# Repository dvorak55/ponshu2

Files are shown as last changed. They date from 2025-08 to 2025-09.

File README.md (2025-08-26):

# ponshu2
The first keyboard in progress by Natural Keyboard Studio Murahana《叢華》.

## プロトタイプ写真  
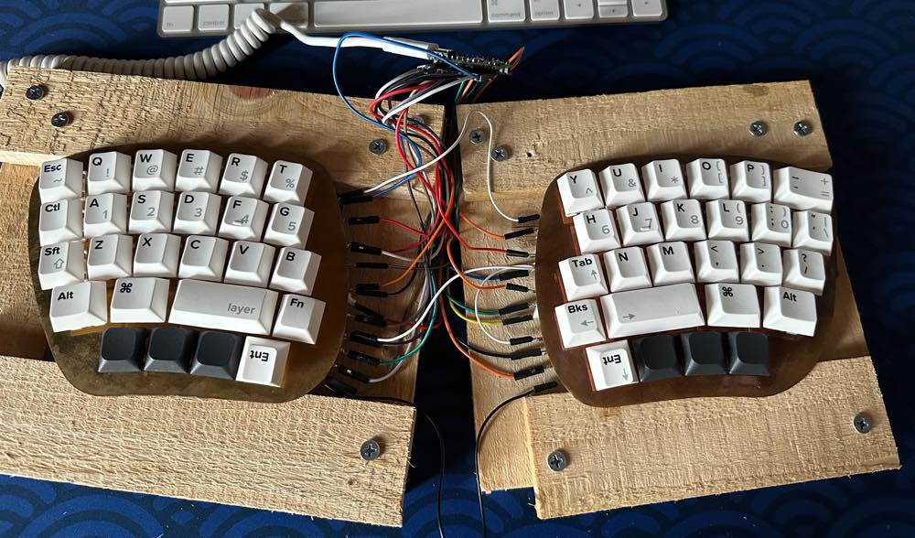
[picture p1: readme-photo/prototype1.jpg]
prototype


自作キーボードを作っています、t-miyajimaです。  
現在、新プロジェクトを進めております。  
新プロジェクトの名前は『Ponshu2（仮）』です。  
これは、以下の特徴を持つキーボードを製造し、販売することが目的です。
- スタイリッシュで使いやすいキーボード
- レイヤードキーボードへの移行が簡単なキー配列
- 修理しやく、長年使い続けられるキーボード
- 配線は基板に頼らず、PCB部分をなるべく少なくする
- 製品全体の廃棄・製造時の環境負荷をなるべく低くする

# 環境負荷の低減
私は、2022年10月から2024年11月にかけて、自作キーボードを作るための工房を自作しました。  
その際に強く思ったのは、前世代の人間が残した遺物は、全て次世代の人間に受け継がれるのだ、ということです。  
そして、受け継がれた不要な遺物を片付けるのは、非常に大変だ、と実感しました。

次世代の人間のために不要な遺物をなるべく残さないようにする活動は、素晴らしいと思います。  
例えば、不要なものを分別してリサイクルすること。  
例えば、ゴミを捨てる際、処分に困るものが発生しないように工夫して物を製造すること。  
例えば、リサイクルしやすいように製造物に含有されるものを明示すること。  
私は、それらに取り組む人たちのことを非常に尊敬しています。

# 自然素材を用いた工房
私が自作したキーボード工房も、そのうち遺物になります。  
だから私は、工房を形作る素材に、自然素材を選びました。  
構造材には、鉄と木材（できる限り接着剤を含まない無垢材）を使用しました。  
断熱材には、炭、動物の毛（羊毛、羽毛）、綿や絹、紙を使用しました。  
これらは自然に還りやすく、片付けがしやすいです。  
また、再利用もしやすいので、次世代の人間がこうむる負担が減ります。  

# キーボードの目標
キーボードに用いる材料も、なるべく自然素材を多く使います。  
現在の私の能力では、コンピュータチップ周辺についてはPCBを使わざるを得ませんが、なるべくサイズを小さくします。  
キーボードのスイッチを保持するプレートには単純な金属を、キーボードのケースには木材を、配線には塩素等のハロゲンを含まないハロゲンフリー電線を、ハンダは鉛フリーハンダを、それぞれ用いる予定です。  
将来的に、より多くの部品を自然素材に置き換えることを目指しております。

# 進捗状況
2025年8月末の時点で、以下を進めております。
- 木材のケースへ取り付けやすく、配線しやすい基板の設計を開始
- キーボードプレートを木材のケースへ取り付けるための、真鍮ネジの選定
- 環境負荷の少ないハロゲンフリー電線の調達

また、以下は完了しております。
- キーボードのキーレイアウト
- キーボードプレートの試作
- キーキャップの試作
- Vialファームウェアの作成
- 試作機の動作テスト（この文章も試作機でタイプしております）

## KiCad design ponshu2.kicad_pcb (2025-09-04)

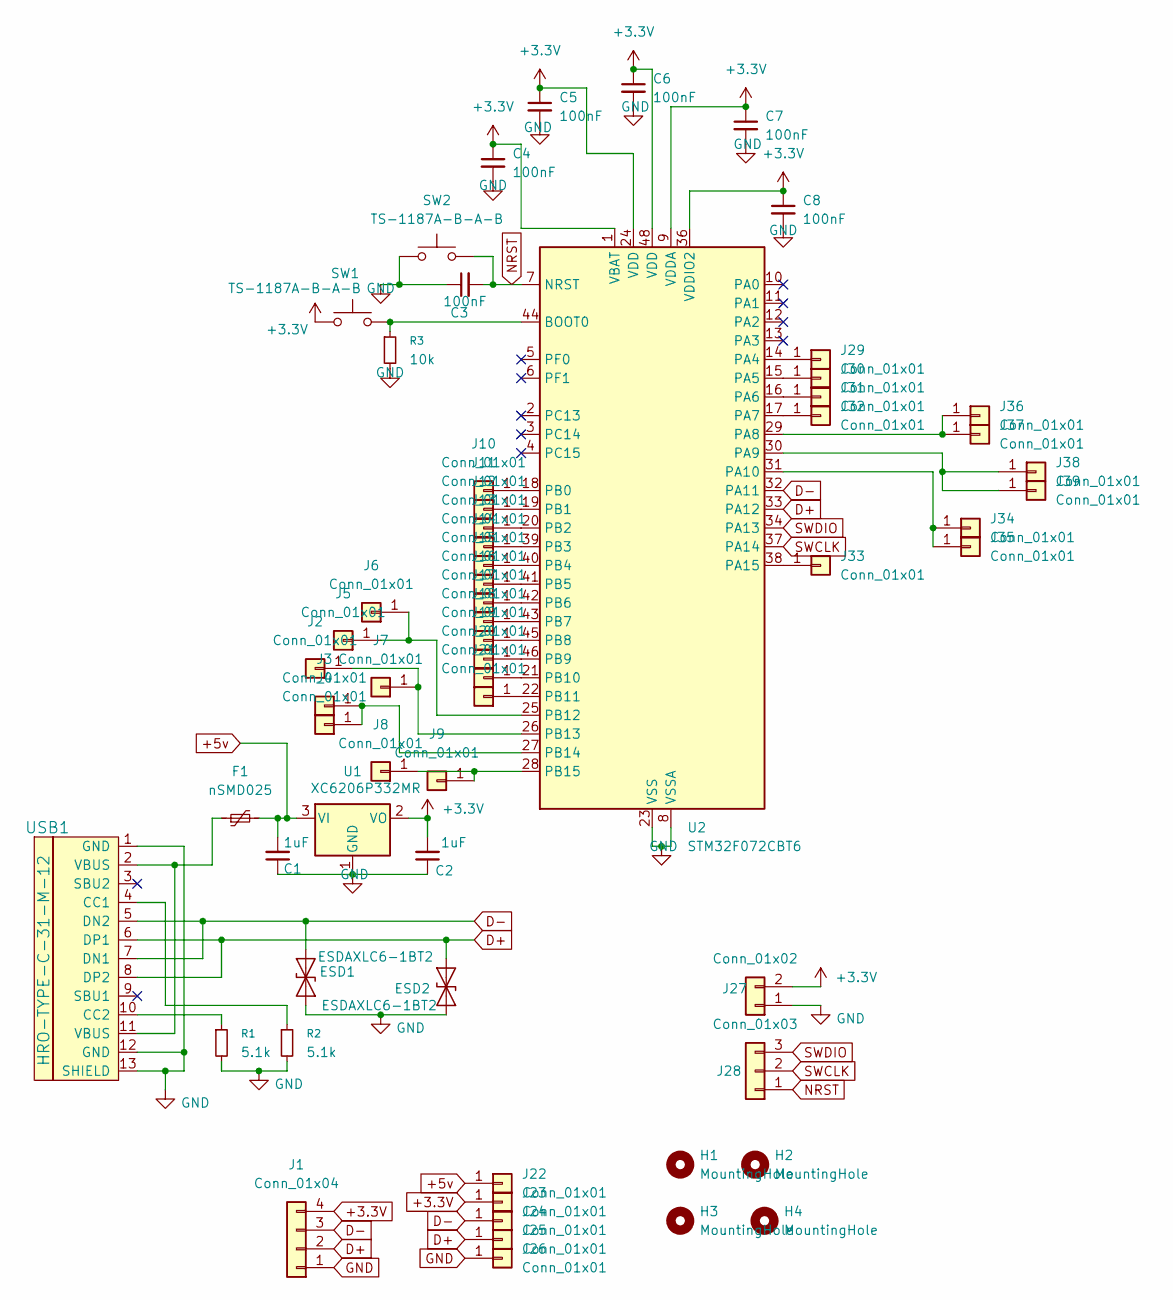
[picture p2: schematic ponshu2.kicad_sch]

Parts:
C1, C2: 1uF; C_0603_1608Metric
C3, C4, C5, C6, C7, C8: 100nF; C_0402_1005Metric
ESD1, ESD2: ESDAXLC6-1BT2; D_0402_1005Metric
F1: nSMD025; Fuse_1206_3216Metric
H1, H2, H3, H4: MountingHole; MountingHole_2.5mm
J1: Conn_01x04; PinHeader_1x04_P2.54mm_Vertical
J2, J3, J4, J5, J6, J7, J8, J9, J10, J11, J12, J13, J14, J15, J16, J17, J18, J19, J20, J21, J22, J23, J24, J25, J26, J29, J30, J31, J32, J33, J34, J35, J36, J37, J38, J39: Conn_01x01; PinHeader_1x01_P2.54mm_Vertical
J27: Conn_01x02; PinHeader_1x02_P2.54mm_Vertical
J28: Conn_01x03; PinHeader_1x03_P2.54mm_Vertical
R1, R2: 5.1k; R_0603_1608Metric
R3: 10k; R_0603_1608Metric
SW1, SW2: TS-1187A-B-A-B; SKQGADE010
U1: XC6206P332MR; SOT-23
U2: STM32F072CBT6; LQFP-48_7x7mm_P0.5mm
USB1: HRO-TYPE-C-31-M-12; HRO-TYPE-C-31-M-12-HandSoldering

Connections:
+3.3V: C2.2, C4.1, C5.1, C6.1, C7.1, C8.1, J1.4, J23.1, J27.2, SW1.1, U1.2 (VO), U2.1 (VBAT), U2.9 (VDDA), U2.24 (VDD), U2.36 (VDDIO2), U2.48 (VDD)
+5v: C1.2, F1.2, J22.1, U1.3 (VI)
D+: ESD2.2 (A2), J1.2, J25.1, U2.33 (PA12), USB1.6 (DP1), USB1.8 (DP2)
D-: ESD1.2 (A2), J1.3, J24.1, U2.32 (PA11), USB1.5 (DN2), USB1.7 (DN1)
GND: C1.1, C2.1, C3.1, C4.2, C5.2, C6.2, C7.2, C8.2, ESD1.1 (A1), ESD2.1 (A1), J1.1, J26.1, J27.1, R1.2, R2.2, R3.2, SW2.1, U1.1 (GND), U2.8 (VSSA), U2.23 (VSS), U2.35 (VSS), U2.47 (VSS), USB1.1 (GND), USB1.12 (GND), USB1.13 (SHIELD)
NRST: C3.2, J28.1, SW2.2, U2.7 (NRST)
unnamed: F1.1, USB1.2 (VBUS), USB1.11 (VBUS)
unnamed: J2.1, J7.1, U2.26 (PB13)
unnamed: J3.1, J4.1, U2.27 (PB14)
unnamed: J5.1, J6.1, U2.25 (PB12)
unnamed: J8.1, J9.1, U2.28 (PB15)
unnamed: J10.1, U2.18 (PB0)
unnamed: J11.1, U2.19 (PB1)
unnamed: J12.1, U2.20 (PB2)
unnamed: J13.1, U2.39 (PB3)
unnamed: J14.1, U2.40 (PB4)
unnamed: J15.1, U2.41 (PB5)
unnamed: J16.1, U2.42 (PB6)
unnamed: J17.1, U2.43 (PB7)
unnamed: J18.1, U2.45 (PB8)
unnamed: J19.1, U2.46 (PB9)
unnamed: J20.1, U2.21 (PB10)
unnamed: J21.1, U2.22 (PB11)
unnamed: J29.1, U2.14 (PA4)
unnamed: J30.1, U2.15 (PA5)
unnamed: J31.1, U2.16 (PA6)
unnamed: J32.1, U2.17 (PA7)
unnamed: J33.1, U2.38 (PA15)
unnamed: J34.1, J35.1, U2.31 (PA10)
unnamed: J36.1, J37.1, U2.29 (PA8)
unnamed: J38.1, J39.1, U2.30 (PA9)
unnamed: R3.1, SW1.2, U2.44 (BOOT0)
unnamed: R2.1, USB1.4 (CC1)
unnamed: R1.1, USB1.10 (CC2)
SWCLK: J28.2, U2.37 (PA14)
SWDIO: J28.3, U2.34 (PA13)

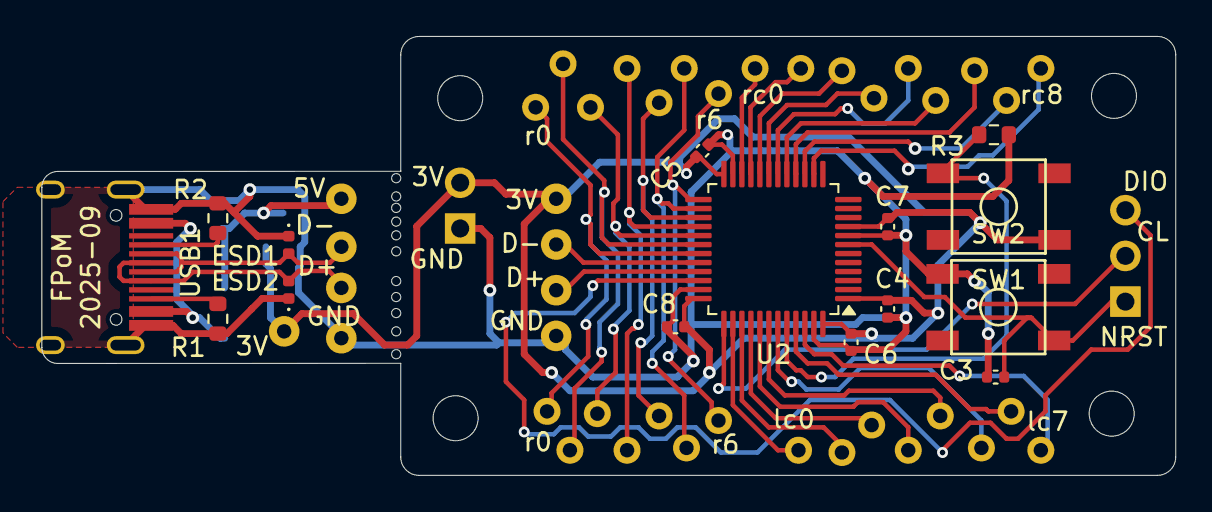
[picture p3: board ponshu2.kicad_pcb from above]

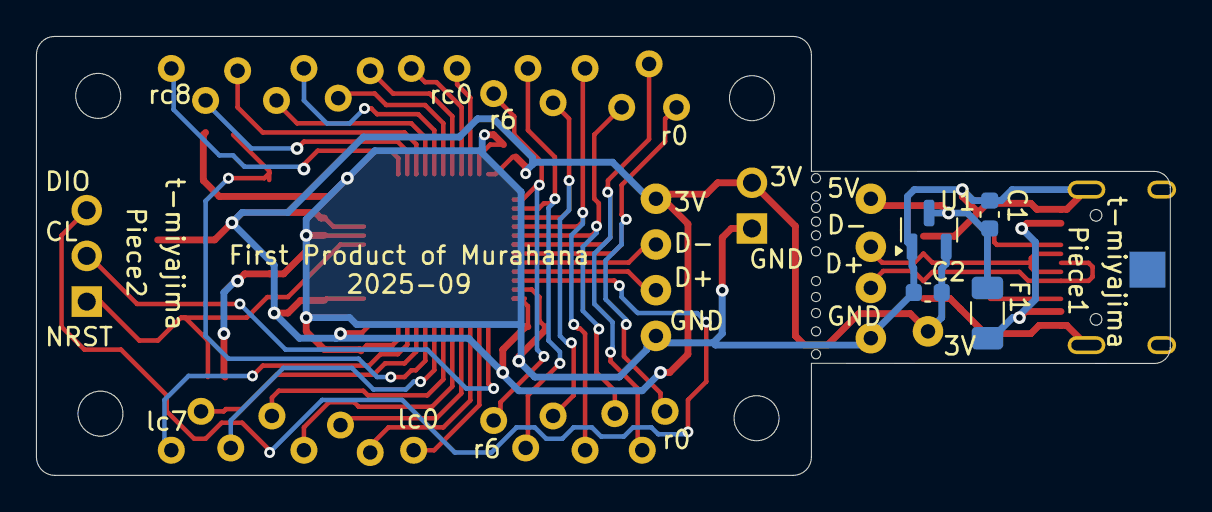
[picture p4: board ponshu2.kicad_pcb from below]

Board: 2 copper layers, 63.0 x 24.4 mm, 62 parts (4 on the bottom side), 36 nets.

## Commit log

2025-08-26 initialize project 2025-8-26
    [ponshu2.kicad_pcb, ponshu2.kicad_sch]
2025-08-26 Update README.md add photo of prototype
2025-08-26 auto update of kicad
2025-08-26 add ai03(GOD) footprints
2025-08-26 create sch file
    [ponshu2.kicad_sch]
2025-08-30 chotto PCB tukutayo
    [ponshu2.kicad_sch]
2025-08-30 PCB daitai owatta kamo
    [ponshu2.kicad_pcb, ponshu2.kicad_sch]
2025-09-02 sukoshi susumeta
    [ponshu2.kicad_pcb, ponshu2.kicad_sch]
2025-09-02 kiban susumeta
    [ponshu2.kicad_pcb, ponshu2.kicad_sch]
2025-09-03 kiban susumetazo!
    [ponshu2.kicad_pcb, ponshu2.kicad_sch]
2025-09-03 kiban no ana kankaku hiroku shita
    [ponshu2.kicad_pcb, ponshu2.kicad_sch]
2025-09-04 kiban hobo kansei shita
    [ponshu2.kicad_pcb]
2025-09-04 kiban kansei
    names of kiban are Piece1 and Piece2
    [ponshu2.kicad_pcb]
